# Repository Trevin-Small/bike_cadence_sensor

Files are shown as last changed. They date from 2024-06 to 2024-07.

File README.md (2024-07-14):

# bike_cadence_sensor
 DIY Cadence Sensor for a Bike, built off an nrf52810 module (Ezurio BL651 453-0005)

Uses a gyroscope to measure rotational velocity, and ANT+ to communicate data to a fitness watch.

Custom PCB, Zephyr RTOS, ANT+ Communication

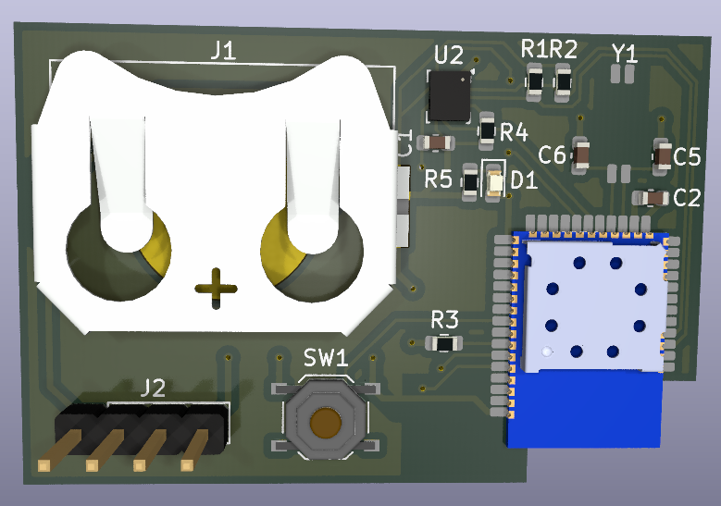
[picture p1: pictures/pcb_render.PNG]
pcb render


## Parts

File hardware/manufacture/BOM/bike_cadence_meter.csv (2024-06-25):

Reference | Value | Footprint | Qty | DNP | JLPCB #
C1,C2 | 100nF | Capacitor_SMD:C_0603_1608Metric | 2 |  | C14663
C5,C6 | 12pF | Capacitor_SMD:C_0603_1608Metric | 2 |  | C38523
D1 | LED | LED_SMD:LED_0603_1608Metric | 1 |  | C2286
J1 | 3034 | Coin_cell_batt:BAT_3034 | 1
J2 | 1x04 | Connector_PinHeader_2.54mm:PinHeader_1x04_P2.54mm_Vertical | 1
R1,R2,R3,R4 | 4.7k | Resistor_SMD:R_0603_1608Metric | 4 |  | C23162
R5 | 100 | Resistor_SMD:R_0603_1608Metric | 1 |  | C22775
SW1 | SW_Push | Button_Switch_SMD:SW_Push_1P1T_XKB_TS-1187A | 1 |  | C318884
TP1,TP2,TP3,TP4 | TestPoint | TestPoint:TestPoint_Pad_D1.0mm | 4
U1 | ~ | Custom Components:Euzrio 453-00005 | 1
U2 | LSM6DS3 | Package_LGA:LGA-14_3x2.5mm_P0.5mm_LayoutBorder3x4y | 1 |  | C967633
Y1 | CM130_9pf_+-20ppm | 32.768khz crystal:CM130 32.768 DZCT | 1

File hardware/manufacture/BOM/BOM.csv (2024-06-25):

Reference | Value | Footprint | Qty | DNP | JLPCB Part #
C1,C2 | 100nF | Capacitor_SMD:C_0603_1608Metric | 2 |  | C14663
C5,C6 | 12pF | Capacitor_SMD:C_0603_1608Metric | 2 |  | C38523
D1 | LED | LED_SMD:LED_0603_1608Metric | 1 |  | C2286
J1 | 3034 | Coin_cell_batt:BAT_3034 | 1 | Y
J2 | 1x04 | Connector_PinHeader_2.54mm:PinHeader_1x04_P2.54mm_Vertical | 1 | Y
R1,R2,R3,R4 | 4.7k | Resistor_SMD:R_0603_1608Metric | 4 |  | C23162
R5 | 100 | Resistor_SMD:R_0603_1608Metric | 1 |  | C22775
SW1 | SW_Push | Button_Switch_SMD:SW_Push_1P1T_XKB_TS-1187A | 1 |  | C318884
U1 | ~ | Custom Components:Euzrio 453-00005 | 1 | Y
U2 | LSM6DS3 | Package_LGA:LGA-14_3x2.5mm_P0.5mm_LayoutBorder3x4y | 1 |  | C967633
Y1 | CM130_9pf_+-20ppm | 32.768khz crystal:CM130 32.768 DZCT | 1 | Y

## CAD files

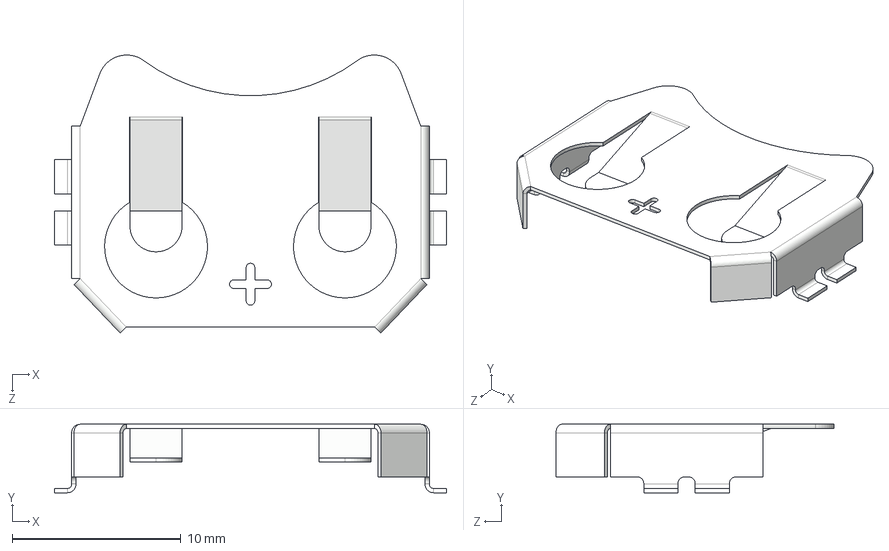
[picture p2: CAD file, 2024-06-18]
hardware/components/3034/3034.step
23.2 x 4.06 x 16.5 mm

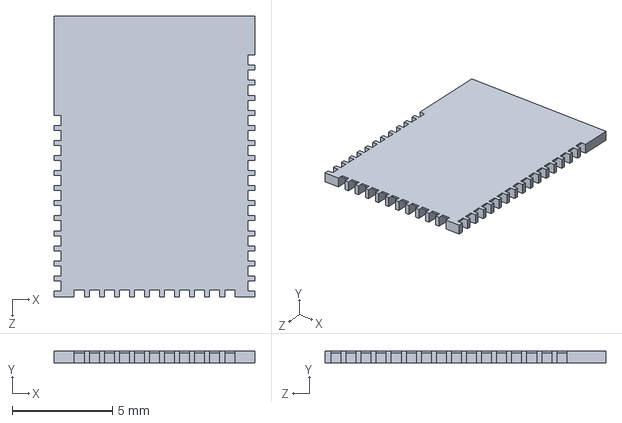
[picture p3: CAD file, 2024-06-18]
hardware/components/BL651 453-0005/BL652 A1 PCB.SLDPRT
10.0 x 0.6 x 14.0 mm

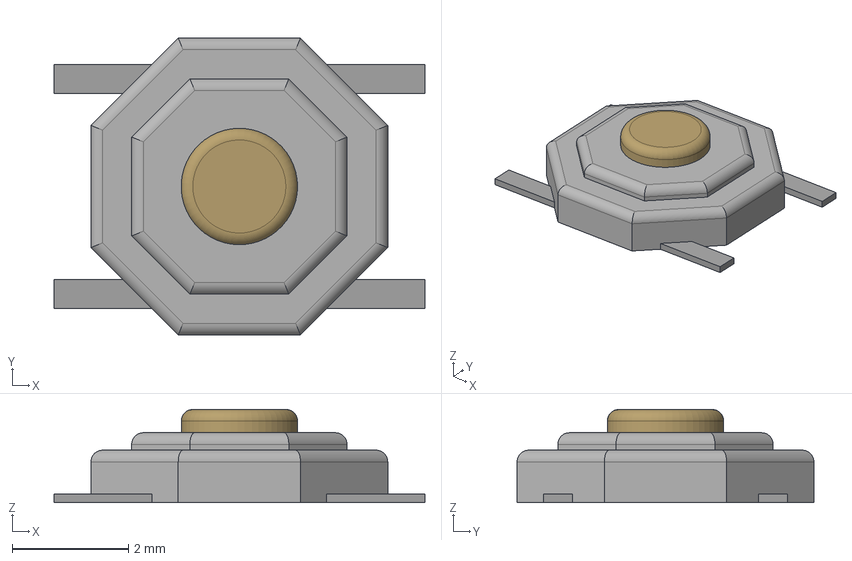
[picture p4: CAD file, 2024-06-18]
hardware/components/TS-1187A/TS-1187A-B-A-B.step
6.38 x 5.10 x 1.60 mm

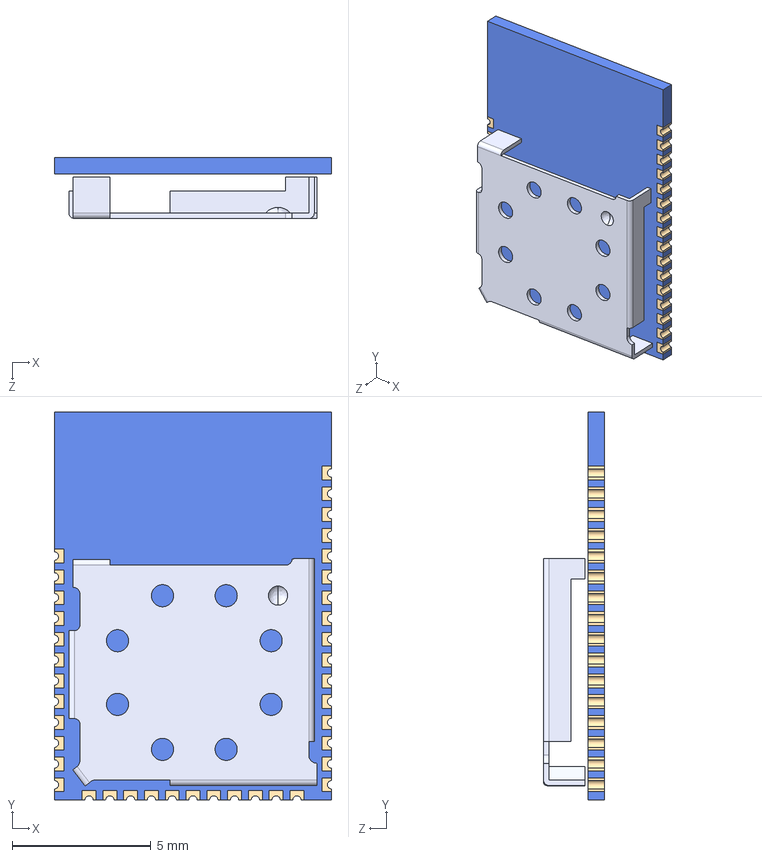
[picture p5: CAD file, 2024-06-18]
hardware/components/BL651 453-0005/BL651 SA.STEP
10.0 x 14.0 x 2.20 mm
BL651 Shield
BL652 A1 PCB
BL652 A1 Pad x 39

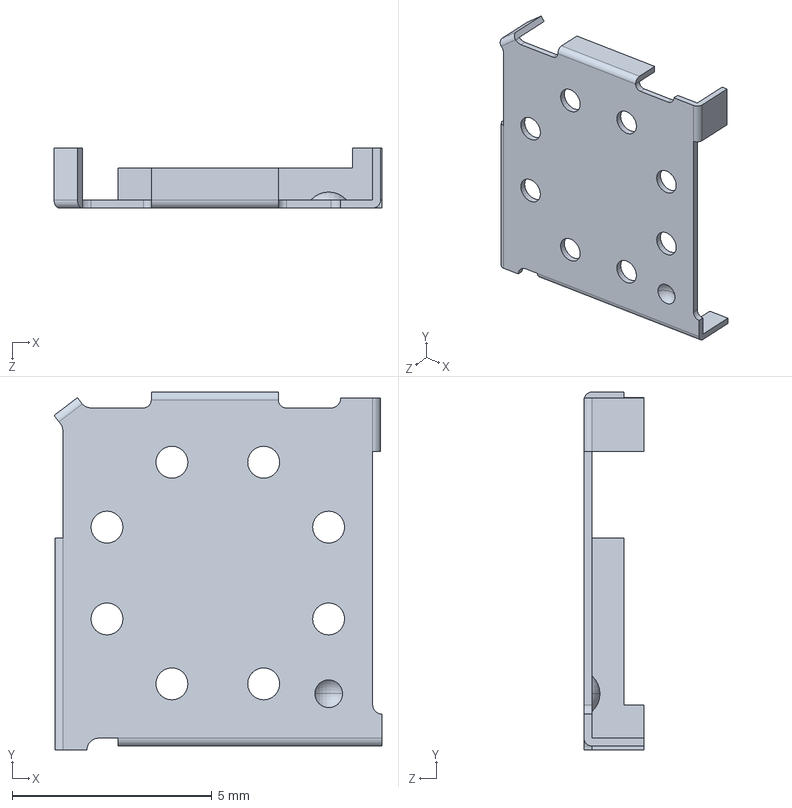
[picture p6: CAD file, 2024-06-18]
hardware/components/BL651 453-0005/BL651 Shield.SLDPRT
8.20 x 8.95 x 1.50 mm

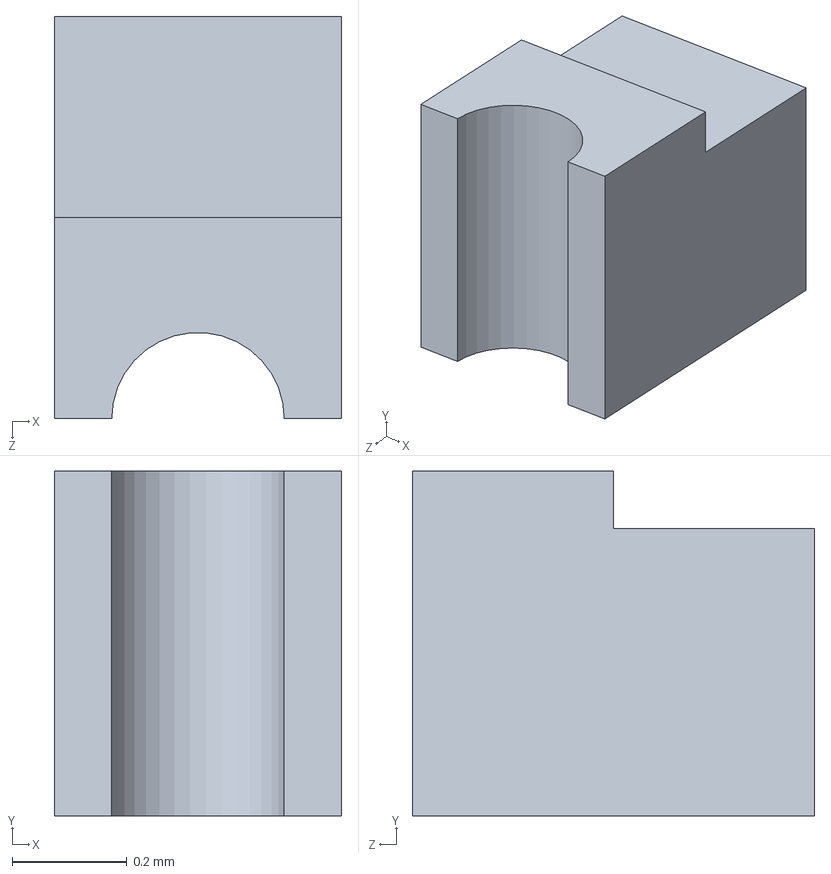
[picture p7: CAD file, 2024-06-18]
hardware/components/BL651 453-0005/BL652 A1 Pad.SLDPRT
0.5 x 0.6 x 0.7 mm

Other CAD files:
hardware/components/BL651 453-0005/BL651 SA.IGS
hardware/components/BL651 453-0005/BL651 SA.SLDASM

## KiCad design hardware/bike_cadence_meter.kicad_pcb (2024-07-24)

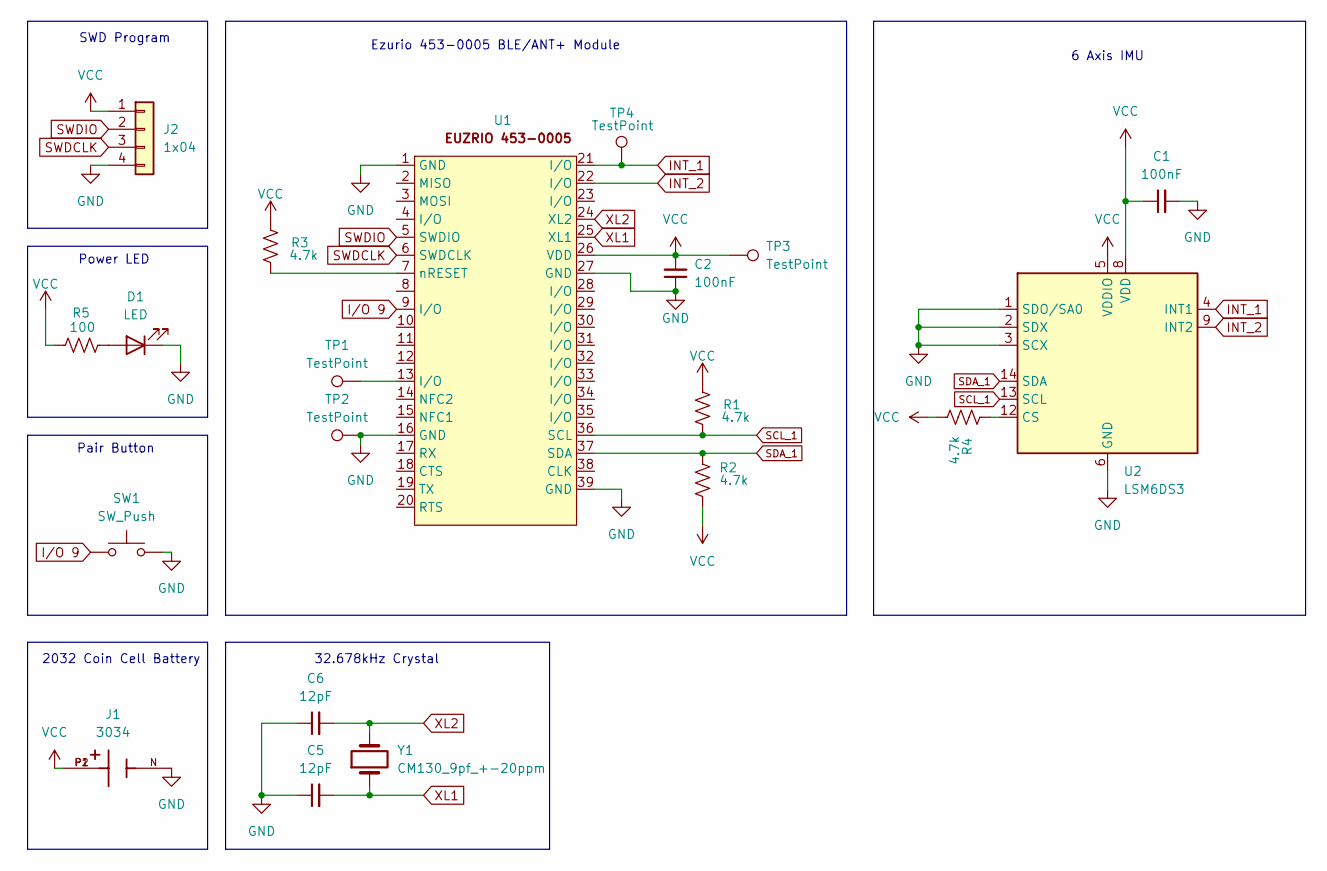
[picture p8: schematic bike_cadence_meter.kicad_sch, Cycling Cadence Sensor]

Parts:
C1, C2: 100nF; C_0603_1608Metric
C5, C6: 12pF; C_0603_1608Metric
D1: LED; LED_0603_1608Metric
J1: 3034; BAT_3034; PARTREV G
J2: 1x04; PinHeader_1x04_P2.54mm_Vertical
R1, R2, R4: 4.7k; R_0603_1608Metric
R3: 4.7k; R_0603_1608Metric; LCSC C23162
R5: 100; R_0603_1608Metric
SW1: SW_Push; SW_Push_1P1T_XKB_TS-1187A
TP1, TP2, TP3, TP4: TestPoint; TestPoint_Pad_D1.0mm
U1: Euzrio 453-00005
U2: LSM6DS3; LGA-14_3x2.5mm_P0.5mm_LayoutBorder3x4y
Y1: CM130_9pf_+-20ppm; CM130 32.768 DZCT

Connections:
GND: C1.2, C2.1, C5.1, C6.1, D1.1 (K), J1.N, J2.4, SW1.2, TP2.1, U1.1 (GND), U1.16 (GND), U1.27 (GND), U1.39 (GND), U2.1 (SDO/SA0), U2.2 (SDX), U2.3 (SCX), U2.6 (GND), U2.7 (GND)
INT_1: TP4.1, U1.21 (I/O), U2.4 (INT1)
INT_2: U1.22 (I/O), U2.9 (INT2)
I/O 9: SW1.1, U1.9 (I/O)
unnamed: D1.2 (A), R5.2
unnamed: TP1.1, U1.13 (I/O)
unnamed: R3.2, U1.7 (nRESET)
unnamed: R4.1, U2.12 (CS)
SCL_1: R1.2, U1.36 (SCL), U2.13 (SCL)
SDA_1: R2.1, U1.37 (SDA), U2.14 (SDA)
SWDCLK: J2.3, U1.6 (SWDCLK)
SWDIO: J2.2, U1.5 (SWDIO)
VCC: C1.1, C2.2, J1.P1, J1.P2, J2.1, R1.1, R2.2, R3.1, R4.2, R5.1, TP3.1, U1.26 (VDD), U2.5 (VDDIO), U2.8 (VDD)
XL1: C5.2, U1.25 (XL1), Y1.1
XL2: C6.2, U1.24 (XL2), Y1.2

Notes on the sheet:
32.678kHz Crystal
Power LED
6 Axis IMU
Ezurio 453-0005 BLE/ANT+ Module
2032 Coin Cell Battery
Pair Button
SWD Program

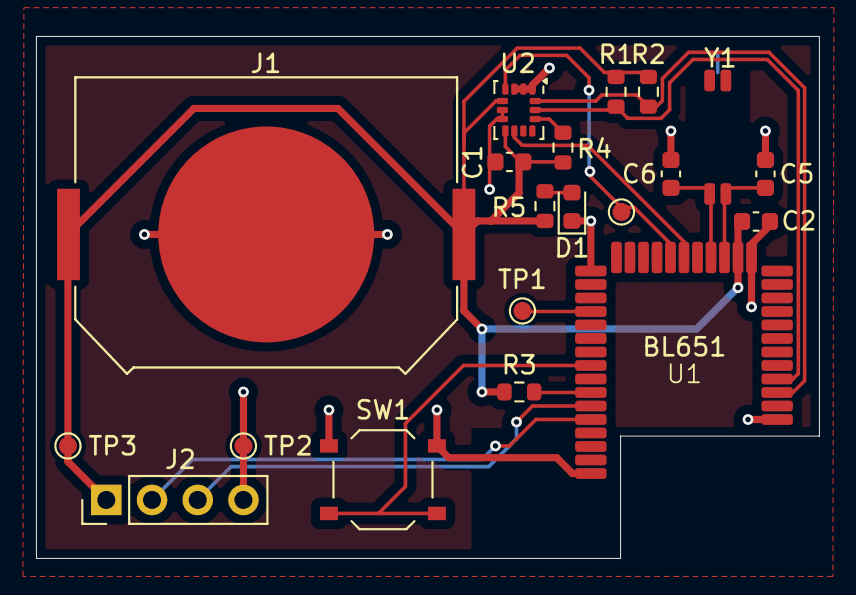
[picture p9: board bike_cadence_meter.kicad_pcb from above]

Board: 2 copper layers, 43.5 x 29.0 mm, 20 parts (0 on the bottom side), 15 nets.

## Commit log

2024-06-18 Added custom footprint/symbol/models
    [3034.step, BL651 SA.IGS, BL651 SA.SLDASM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]
2024-06-18 Add pcb render, bl651 model
2024-06-18 update model in pcb
    [bike_cadence_meter.kicad_pcb]
2024-06-25 Add manufacturing files
    [BOM.csv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]
2024-07-24 Fixed reversed LED
    [bike_cadence_meter.kicad_pcb, bike_cadence_meter.kicad_sch]
